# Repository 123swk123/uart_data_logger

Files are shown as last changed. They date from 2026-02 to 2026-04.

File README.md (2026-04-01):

# UART data logger to SD card

> [!NOTE]
> *Work in progress...*

This is a simple UART data logger, logger saves the data to FAT(12/16/32) formatted SD card.

## Schematic

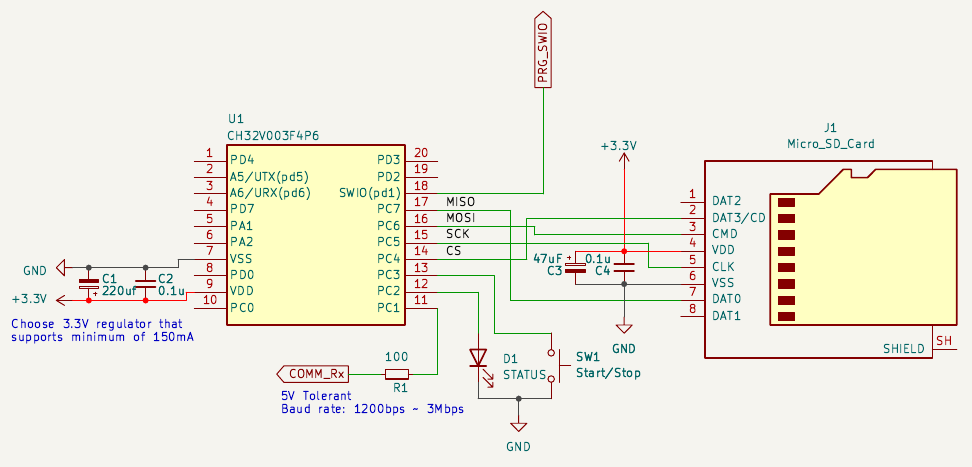
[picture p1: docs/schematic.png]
Schematic

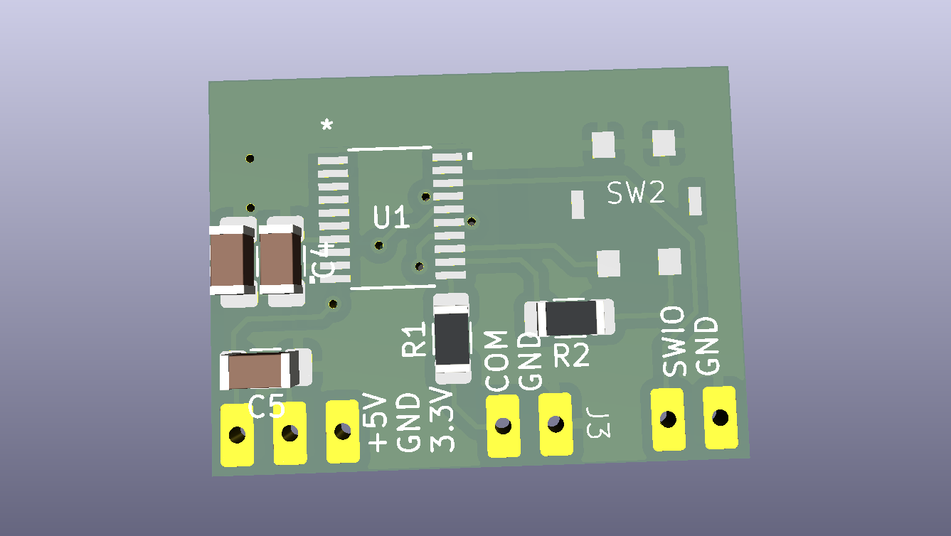
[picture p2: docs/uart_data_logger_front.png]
PCB Front

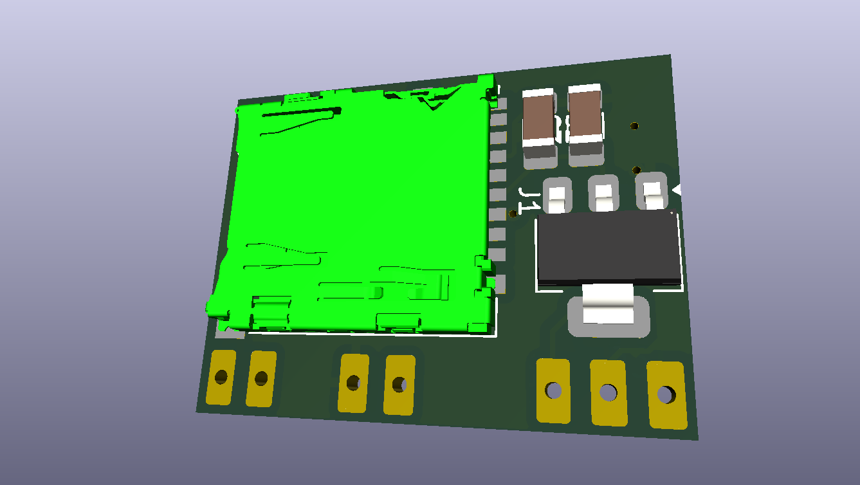
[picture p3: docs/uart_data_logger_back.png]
PCB Back


## Preparations

- Any SDHC card should work, but I have tested them upto 8GB
- Format the card as FAT12/16/32
- copy the [config.txt](src/card_config/config.txt) and [head](src/card_config/head) to root of the SD card

## How to use the logger

- After power-on the status LED will be OFF
- start/stop button is a simple toggle switch
    - press once to start logging
    - press again to stop logging
- Always remove the card when status LED is OFF.

| Status LED | Remarks |
|--|--|
| OFF | Logger stopped, free to remove the SD card after powering down |
| ON | Logger running, do not remove the card |
| Constant blinking | Logger error |
| Brief pulsing |  Actively logging the received UART data |

### config.txt

first 2 lines are comment and they are skipped during the configuration process

3rd line describes the serial port configuration.
> `s<no>:baud rate,data bits<8,9>,parity<0,1,2>,stop bits<1,2>,output formatter<c,d,x,X>,seq start char,seq end char`
```
s<no>:    Serial port number, starting from 1
range:    1 to Maximum no.of UART HW supported by the controller, in case of CH32V003 its just 1.
Example:  s1
```
```
baud rate:  UART logger baud rate
range:      1200 ~ 300000 (check CH32v003 reference manual to calculate the percentage error due to divider round off)
Example:    115200
```
```
data bits:  UART logger data bits per frame
range:      8, 9
Example:    8
```
```
parity:   UART data partiy enable/disable
range:    0 - No parity (disabled)
          1 - odd parity
          2 - even parity
Example:  0
```
```
stop bits:  No.of stop bits per frame
range:      1, 2
Example:    1
```
```
output formatter: logger output encode format
range:            c - store the UART data in a transparent 8-bit ASCII raw
                  u - store the UART data as unsigned decimal value
                  x - store the UART data as hexadecimal value
                  X - store the UART data as hexadecimal value (all caps)
Example:          x
```
```
seq start char: a 9-bit unsigned integer. Upon reciving this character logger notes the event time stamp at start of the row/line
                and the logger continues to log the sub-sequent received data in the same row/line as per the output format
                Note: This seq start character will not be logged.
                      time stamp format: hour.minute.seconds.milli second (resolution: 100milli)
range:          0 ~ 511
Example:        13 (\r)
```
```
seq stop char:  a 9-bit unsigned integer. Upon reciving this character logger closes the current row/line with \r\n and
                creates a new row/line, then the logger waits for seq start character.
                Note: seq stop character will not be logged; Seq start and stop char can be the same.
range:          0 ~ 511
Example:        10 (\n)
```

4th line describes the time offset information.
> `t:year,month,day,hour,minute`
```
t:  start of time offset definition

year:     unsigned 16bit integer
range:    > 1980
Example:  2026

month:    unsigned 16bit integer
range:    1 ~ 12
Example:  2

day:      unsigned 16bit integer
range:    1 ~ 31
Example:  10

hour:     unsigned 16bit integer
range:    0 ~ 23
Example:  22

minute:   unsigned 16bit integer
range:    0 ~ 59
Example:  0
```

### Reasons for logger error

1. SD card not present
2. SD card format not recognized, so unable to mount
3. missing [config.txt](src/card_config/config.txt) in the root of SD card
4. missing [head](src/card_config/head) in the root of SD card
5. Invalid / Un-recognizable contents in [config.txt](src/card_config/config.txt) or [head](src/card_config/head)

## [How to build](docs/build.md)

## Tested features

> [!WARNING]
> Not all aspects of the functionality was tested (This was a side project)

- SDHC card upto 8GB
- Tested baud
  - 115200
  - 750000
  - 921600
- Data bits
  - 8
  - 9
- Parity
  - None
- Stop bits
  - 2
- Logging format
  - `c` - ASCII characters
  - `u` - unsigned decimal
  - `x`/`X` - Hexadecimal
- Seq start/Seq stop
  - `\r`
  - `0xFF`
  - `0x1CC`

### Sample log output
[Test log results](docs/log_output.md)

### Thanks to various open source code base helped realizing the project

- Framework [ch32fun](https://github.com/cnlohr/ch32fun)
- SD Card driver [modified sample driver from ChaN](https://elm-chan.org/docs/mmc/mmc_e.html)
- FAT(12/16/32) library [ChaN's FatFs](https://elm-chan.org/fsw/ff/)
- [Aleksej Muratov's sscanf](https://github.com/MuratovAS/mini-scanf) modified for this project to further reduce the ROM size

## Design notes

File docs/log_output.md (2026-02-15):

# Logger output

This logger in [APP_CONF_RUNNING_LOG](../src/app/uart_logger/Makefile#L14) mode simply creates a log file with running number under the root directory.
Every time when you push the key to start logging, logger reads the [head](../src/card_config/head) file to find the last used log file name and creates the next one.

## SD card root folder listing
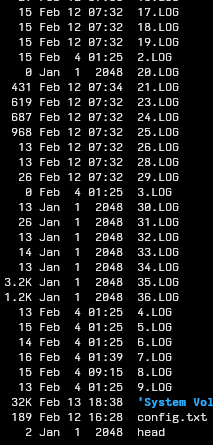
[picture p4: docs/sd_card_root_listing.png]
Logger SD card


## Log file output

### [test1 - 8bit ASCII/transparent logging](../tests/test1.tio.lua) @ 921600bps
```log
[0:5:11.0]ASCII test line 1
[0:5:15.100]ASCII test line 2
[0:5:15.200]Dolor pariatur ipsum nisi dolore culpa in sunt Lorem est. Elit exercitation ut cillum minim velit consequat irure laboris voluptate aliqua ex nisi eu incididunt. Labore excepteur ut pariatur labore culpa esse cillum irure ex cillum sunt fugiat do nisi. Officia irure excepteur ad sint pariatur dolor. Tempor dolor tempor laborum.
[0:5:15.300]Esse non do amet pariatur esse proident. Irure labore cillum est commodo. C consequat.
[0:5:15.300]Lorem labore voluptate officia non deserunt laboris ea. Nulla officia nulla sint deserunt quis ullamco sint laborum. Anim excepteur cillum dolor consequat laborum occaecat dolor minim. Aute nisi ullamco excepteur qui minim duis ex. Dolore deserunt in fugiat ex non elit quis id laboris pariatur minim. Velit aliqua ad consectetur nostrud id enim culpa commodo dolore incididunt incididunt. Cillum veniam consectetur labore consectetur quis ea quis excepteur. Do est aute reprehenderit dolor culpa ea in fugiat consectetur consectetur culpa consequat voluptate.
[0:5:15.400]Elit labore voluptate tempor est nostrud consequat esse enim et consectetur. Velit cupidatat aliqua commodo irure magna eiusmod ea duis ullamco eu voluptate laborum id occaecat. Aliquip deserunt proident exercitation. Sit aliquip sit elit consectetur nulla dolor consectetur dolor occaecat cupidatat proident veniam ea qui laboris. Pariatur esse dolor anim. Non laborum duis nulla laborum fugiat tempor quis cillum aliqua anim.
[0:5:15.500]Reprehenderit aliqua ut pariatur laboris dolor pariatur ex proident aute aliqua veniam Lorem elit ex. Id est elit qui ipsum id consequat deserunt enim eu eiusmod sit labore quis. Sunt et minim officia labore occaecat et anim commodo non ex cillum irure amet Lorem dolor. Eu pariatur culpa irure in aliqua amet non pariatur eu exercitation Lorem.
```

### [test2 - hexadecimal encoded logging](../tests/test2.tio.lua) @ 921600bps
```log
[0:23:15.800]1 2 3 4 5 6 7 8 9 a b c 
[0:23:26.800]e f 
[0:23:26.800]1 2 3 4 5 6 7 8 9 a b c 
[0:23:26.900]e f 10 11 12 13 14 15 16 17 18 19 1a 1b 1c 1d 1e 1f 
[0:23:26.900]1 2 3 4 5 6 7 8 9 a b c 
[0:23:27.0]e f 10 11 12 13 14 15 16 17 18 19 1a 1b 1c 1d 1e 1f 20 21 22 23 24 25 26 27 28 29 2a 2b 2c 2d 2e 2f 30 31 32 33 34 35 36 37 38 39 3a 3b 3c 3d 3e 3f 
[0:23:27.0]1 2 3 4 5 6 7 8 9 a b c 
[0:23:27.0]e f 10 11 12 13 14 15 16 17 18 19 1a 1b 1c 1d 1e 1f 20 21 22 23 24 25 26 27 28 29 2a 2b 2c 2d 2e 2f 30 31 32 33 34 35 36 37 38 39 3a 3b 3c 3d 3e 3f 40 41 42 43 44 45 46 47 48 49 4a 4b 4c 4d 4e 4f 50 51 52 53 54 55 56 57 58 59 5a 5b 5c 5d 5e 5f 60 61 62 63 64 65 66 67 68 69 6a 6b 6c 6d 6e 6f 70 71 72 73 74 75 76 77 78 79 7a 7b 7c 7d 7e 7f 
[0:23:27.0]1 2 3 4 5 6 7 8 9 a b c 
[0:23:27.100]e f 10 11 12 13 14 15 16 17 18 19 1a 1b 1c 1d 1e 1f 20 21 22 23 24 25 26 27 28 29 2a 2b 2c 2d 2e 2f 30 31 32 33 34 35 36 37 38 39 3a 3b 3c 3d 3e 3f 40 41 42 43 44 45 46 47 48 49 4a 4b 4c 4d 4e 4f 50 51 52 53 54 55 56 57 58 59 5a 5b 5c 5d 5e 5f 60 61 62 63 64 65 66 67 68 69 6a 6b 6c 6d 6e 6f 70 71 72 73 74 75 76 77 78 79 7a 7b 7c 7d 7e 7f 80 81 82 83 84 85 86 87 88 89 8a 8b 8c 8d 8e 8f 90 91 92 93 94 95 96 97 98 99 9a 9b 9c 9d 9e 9f a0 a1 a2 a3 a4 a5 a6 a7 a8 a9 aa ab ac ad ae af b0 b1 b2 b3 b4 b5 b6 b7 b8 b9 ba bb bc bd be bf c0 c1 c2 c3 c4 c5 c6 c7 c8 c9 ca cb cc cd ce cf d0 d1 d2 d3 d4 d5 d6 d7 d8 d9 da db dc dd de df e0 e1 e2 e3 e4 e5 e6 e7 e8 e9 ea eb ec ed ee ef f0 f1 f2 f3 f4 f5 f6 f7 f8 f9 fa fb fc fd fe ff
```

### [test3 - decimal encoded logging](../tests/test3.tio.lua) @ 921600bps
```log
[0:0:4.200]0 1 2 3 4 5 6 7 8 9 10 11 12 13 14 15 
[0:1:14.200]0 1 2 3 4 5 6 7 8 9 10 11 12 13 14 15 16 17 18 19 20 21 22 23 24 25 26 27 28 29 30 31 
[0:1:15.200]0 1 2 3 4 5 6 7 8 9 10 11 12 13 14 15 16 17 18 19 20 21 22 23 24 25 26 27 28 29 30 31 32 33 34 35 36 37 38 39 40 41 42 43 44 45 46 47 48 49 50 51 52 53 54 55 56 57 58 59 60 61 62 63 
[0:1:16.200]0 1 2 3 4 5 6 7 8 9 10 11 12 13 14 15 16 17 18 19 20 21 22 23 24 25 26 27 28 29 30 31 32 33 34 35 36 37 38 39 40 41 42 43 44 45 46 47 48 49 50 51 52 53 54 55 56 57 58 59 60 61 62 63 64 65 66 67 68 69 70 71 72 73 74 75 76 77 78 79 80 81 82 83 84 85 86 87 88 89 90 91 92 93 94 95 96 97 98 99 100 101 102 103 104 105 106 107 108 109 110 111 112 113 114 115 116 117 118 119 120 121 122 123 124 125 126 127 
[0:1:17.200]0 1 2 3 4 5 6 7 8 9 10 11 12 13 14 15 16 17 18 19 20 21 22 23 24 25 26 27 28 29 30 31 32 33 34 35 36 37 38 39 40 41 42 43 44 45 46 47 48 49 50 51 52 53 54 55 56 57 58 59 60 61 62 63 64 65 66 67 68 69 70 71 72 73 74 75 76 77 78 79 80 81 82 83 84 85 86 87 88 89 90 91 92 93 94 95 96 97 98 99 100 101 102 103 104 105 106 107 108 109 110 111 112 113 114 115 116 117 118 119 120 121 122 123 124 125 126 127 128 129 130 131 132 133 134 135 136 137 138 139 140 141 142 143 144 145 146 147 148 149 150 151 152 153 154 155 156 157 158 159 160 161 162 163 164 165 166 167 168 169 170 171 172 173 174 175 176 177 178 179 180 181 182 183 184 185 186 187 188 189 190 191 192 193 194 195 196 197 198 199 200 201 202 203 204 205 206 207 208 209 210 211 212 213 214 215 216 217 218 219 220 221 222 223 224 225 226 227 228 229 230 231 232 233 234 235 236 237 238 239 240 241 242 243 244 245 246 247 248 249 250 251 252 253
```

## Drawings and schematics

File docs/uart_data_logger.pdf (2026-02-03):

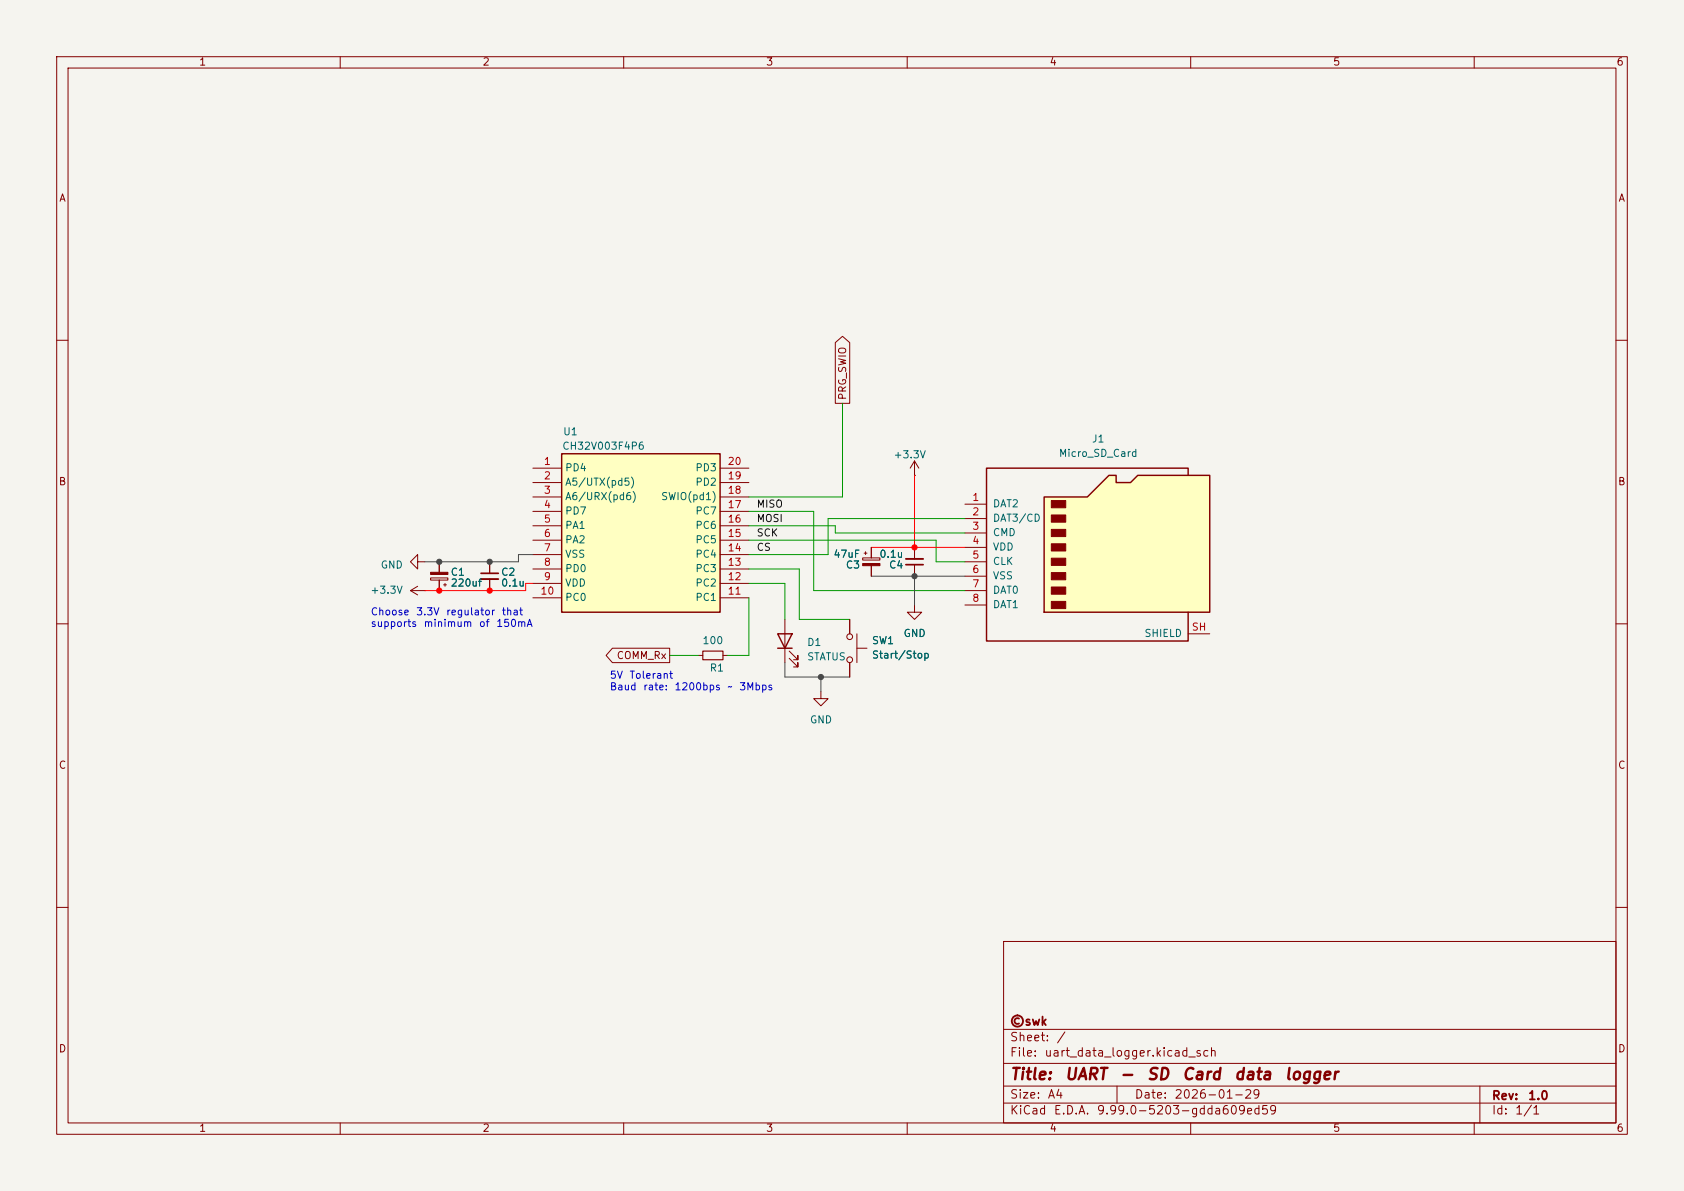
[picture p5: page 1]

Sheet: /
D Date: 2026-01-29 KiCad E.D.A. 9.99.0-5203-gdda609ed59
File: uart_data_logger.kicad_sch
Title: UART - SD Card data logger

Size: A4 | Rev: 1.0

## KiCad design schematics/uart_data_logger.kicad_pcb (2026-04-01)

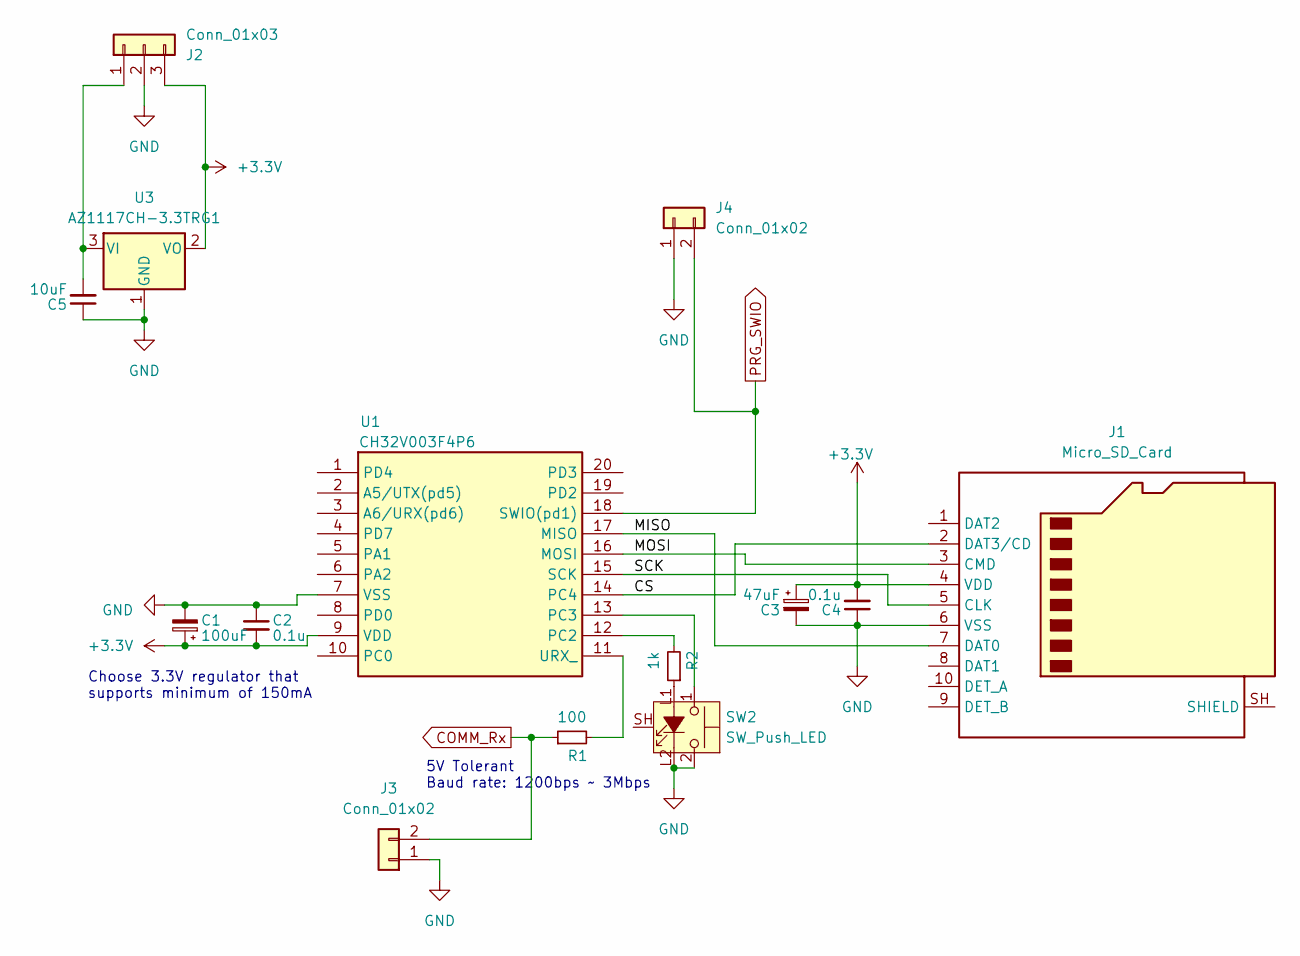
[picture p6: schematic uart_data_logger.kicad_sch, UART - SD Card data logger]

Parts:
C1: 100uF; C_1206_3216Metric_Pad1.33x1.80mm_HandSolder
C2, C4: 0.1u; C_1206_3216Metric_Pad1.33x1.80mm_HandSolder
C3: 47uF; C_1206_3216Metric_Pad1.33x1.80mm_HandSolder
C5: 10uF; C_1206_3216Metric_Pad1.33x1.80mm_HandSolder
J1: Micro_SD_Card; microSD_HC_Hirose_DM3AT-SF-PEJM5
J2: Conn_01x03; 1x03_THT_P2.54mm
J3, J4: Conn_01x02; 1x02_THT_P2.54mm
R1: 100; R_1206_3216Metric_Pad1.30x1.75mm_HandSolder
R2: 1k; R_1206_3216Metric_Pad1.30x1.75mm_HandSolder
SW2: SW_Push_LED; SW_Push_LED_AK104238
U1: CH32V003F4P6; TSSOP20
U3: AZ1117CH-3.3TRG1; SOT-223-3_TabPin2

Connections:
+3.3V: C1.1, C2.2, C3.1, C4.2, J1.4 (VDD), J2.3, U1.9 (VDD), U3.2 (VO)
/CS: J1.2 (DAT3/CD), U1.14 (PC4)
/MISO: J1.7 (DAT0), U1.17 (MISO)
/MOSI: J1.3 (CMD), U1.16 (MOSI)
/SCK: J1.5 (CLK), U1.15 (SCK)
COMM_Rx: J3.2, R1.1
GND: C1.2, C2.1, C3.2, C4.1, C5.1, J1.6 (VSS), J2.2, J3.1, J4.1, SW2.2, SW2.L2, U1.7 (VSS), U3.1 (GND)
unnamed: C5.2, J2.1, U3.3 (VI)
unnamed: R2.1, SW2.L1
unnamed: R1.2, U1.11 (URX_)
unnamed: R2.2, U1.12 (PC2)
unnamed: SW2.1, U1.13 (PC3)
PRG_SWIO: J4.2, U1.18 (SWIO(pd1))

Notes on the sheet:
5V Tolerant Baud rate: 1200bps ~ 3Mbps
Choose 3.3V regulator that supports minimum of 150mA

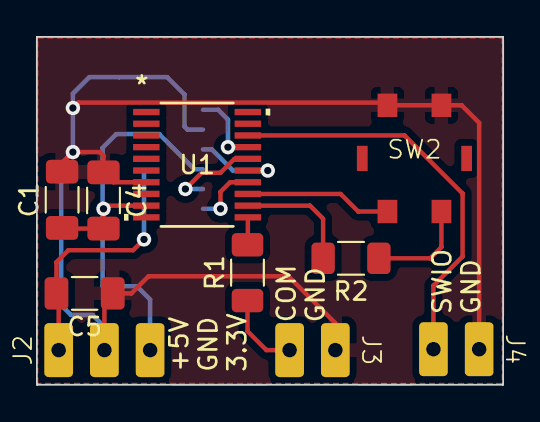
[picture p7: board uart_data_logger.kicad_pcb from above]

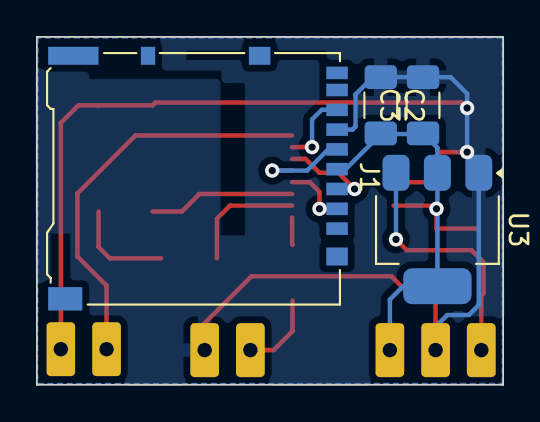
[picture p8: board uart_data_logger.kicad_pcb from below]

Board: 2 copper layers, 25.9 x 19.3 mm, 14 parts (4 on the bottom side), 13 nets.

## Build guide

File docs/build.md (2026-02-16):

# To Build...

## RISCV gcc toolchain

Download and extract either one of those based on your Ubuntu version and ensure that `bin` folder of the extracted path is in your environment variable's `PATH` list

[riscv64-uclibc-ng-ubuntu-22.04-gcc.tar.xz](https://github.com/riscv-collab/riscv-gnu-toolchain/releases/download/2026.02.13/riscv64-uclibc-ng-ubuntu-22.04-gcc.tar.xz)
[riscv64-uclibc-ng-ubuntu-24.04-gcc.tar.xz](https://github.com/riscv-collab/riscv-gnu-toolchain/releases/download/2026.02.13/riscv64-uclibc-ng-ubuntu-24.04-gcc.tar.xz)

## Compilation

Walk through the [Makefile]() and [app_base.h]() to understand the available various pre-compilation options.
by the way the default setting is the optimized version that is suitable for most of the use case(s)

### To compile without any debug print

> [!NOTE]
> Debug print uses semi-hosting mechanism to send the log that are invoked via printf(...) calls, so you need debugger connected to view the logs

`make -C src/app/uart_logger DEBUG=0`

### To compile with debug print

`make -C src/app/uart_logger`

### To generate intellisense support file

`make -C src/app/uart_logger clangd`

### To clean

`make -C src/app/uart_logger clangd_clean clean`

## [Pre-built binaries](https://github.com/123swk123/uart_data_logger/releases)

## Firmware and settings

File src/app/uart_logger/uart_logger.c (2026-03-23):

#include "drv_systick.h"
#include "app_base.h"

#include "ch32fun.h"
#include "ch32v003hw.h"
#include "ff.h"

#if (FF_MULTI_PARTITION == 1)
PARTITION VolToPart[FF_VOLUMES] = {
  {0, 1},     /* "0:" ==> 1st partition on the pd#0 */
};
#endif

FATFS gFsFAT;
FIL ghFile;

static uint16_t gu16buffRx[APP_UART_RX_BUFF_SZ];

#if (APP_CONF_CACHE_BUFF)
char gbuffCache[FF_MIN_SS+30];
static uint32_t gidxCacheWr = 0;
#endif

stHMI gHMI;
stCFGLog gCfgLog;

int _write(int fd,
           const char *buf,
           int size) {
  int i = 0;
  int writeSize = size;

  #if 0
  volatile union {
    uint32_t u32;
    struct {
      uint8_t b3;
      uint8_t b4;
      uint8_t b5;
      uint8_t b6;
    };
  } *data1;
  volatile union {
    uint32_t u32;
    struct {
      uint8_t sz;
      uint8_t b0;
      uint8_t b1;
      uint8_t b2;
    };
  } *data0 = (void *)&size;
  #endif
  do {
    /**
     * data0  data1 8 bytes
     * data0 The lowest byte storage length, the maximum is 7
     *
     */
    while (*(DMDATA0) != 0u)
      ;

    if (writeSize > 7) {
      *(DMDATA1) = (*(buf + i + 3)) | (*(buf + i + 4) << 8) | (*(buf + i + 5) << 16) | (*(buf + i + 6) << 24);
      // data1.b3 = *(buf+i+3);
      // data1.b4 = *(buf+i+4);
      // data1.b5 = *(buf+i+5);
      // data1.b6 = *(buf+i+6);
      // *(DMDATA1) = data1.u32;

      *(DMDATA0) = (7u) | (*(buf + i) << 8) | (*(buf + i + 1) << 16) | (*(buf + i + 2) << 24);
      // data0->b2 = *(buf+i+2);
      // data0->b1 = *(buf+i+1);
      // data0->b0 = *(buf+i+0);
      // data0->sz = writeSize;
      // *(DMDATA0) = data0->u32;

      i += 7;
      writeSize -= 7;
    } else {
      *(DMDATA1) = (*(buf + i + 3)) | (*(buf + i + 4) << 8) | (*(buf + i + 5) << 16) | (*(buf + i + 6) << 24);
      // data1.b3 = *(buf+i+3);
      // data1.b4 = *(buf+i+4);
      // data1.b5 = *(buf+i+5);
      // data1.b6 = *(buf+i+6);
      // *(DMDATA1) = data1.u32;

      *(DMDATA0) = (writeSize) | (*(buf + i) << 8) | (*(buf + i + 1) << 16) | (*(buf + i + 2) << 24);
      // data0->b2 = *(buf+i+2);
      // data0->b1 = *(buf+i+1);
      // data0->b0 = *(buf+i+0);
      // data0->sz = writeSize;
      // *(DMDATA0) = data0->u32;

      writeSize = 0;
    }
  } while (writeSize);
  return size;
}

static char *_f_gets(char *buff,
                     FIL *f) {
  UINT nBytesAccessed;
  char c = '\0';

  if (buff == NULL) {
    // skip this line
    while (c != '\n') {
      f_read(f, &c, 1, &nBytesAccessed);
      if (nBytesAccessed == 0) {
        break;
      }
    }
    return buff;
  } else {
    while (c != '\n') {
      f_read(f, &c, 1, &nBytesAccessed);
      if (nBytesAccessed == 0) {
        *buff++ = '\0';
        break;
      }
      if (c == '\n')
        *buff++ = '\0';
      else if (c != '\r')
        *buff++ = c;
    }
    return buff;
  }
}

static inline FRESULT doConfig(void) {
  FRESULT rslt = f_open(&ghFile, "config.txt", FA_READ);
  int tmp;
  if (rslt == FR_OK) {
    #if (APP_CONF_CACHE_BUFF == 1)
    #define buff gbuffCache
    #else
    char buff[40];
    #endif
    char *pBuff;
    struct {
      uint32_t uBaud;
      uint32_t uBits;
      uint32_t uParity;
      uint32_t uStop;
    } cfgUART;

// skip the first 2 comment line
#if 0
        UINT nBytesAccessed;
        tmp = 0;
        while(tmp < 2) {
            f_read(&ghFile, buff, 1, &nBytesAccessed);
            if(nBytesAccessed == 0) {rslt = FR_INVALID_PARAMETER;goto _doConfig_Exit;}
            if(buff[0] == '\n')
                tmp++;
        }
#else
    _f_gets(NULL, &ghFile);
    _f_gets(NULL, &ghFile);
#endif

    // read uart1 config
    // pBuff = f_gets(buff, sizeof(buff)-1, &ghFile);
    pBuff = _f_gets(buff, &ghFile);
    if (pBuff == 0) {
      rslt = FR_INVALID_PARAMETER;
      goto _doConfig_Exit;
    }
    puts_dbg(buff);
    // skip first 3 chars 's1:'
    tmp = c_sscanf(&buff[3], "%u%u%u%u%*c%c%u%u", &cfgUART.uBaud, &cfgUART.uBits, &cfgUART.uParity, &cfgUART.uStop,
                   &gCfgLog.cOutputFormatter, &gCfgLog.uSeqStart, &gCfgLog.uSeqStop);
    printf_dbg("s1:%u,%u,%u,%u,%u,%u,%c|\n", cfgUART.uBaud, cfgUART.uBits, cfgUART.uParity, cfgUART.uStop, gCfgLog.uSeqStart,
            gCfgLog.uSeqStop, gCfgLog.cOutputFormatter);
    if (tmp != 8) {
      rslt = FR_INVALID_PARAMETER+1;
      goto _doConfig_Exit;
    }

#define CTLR1_UE_Set   ((uint16_t)0x2000) /* USART Enable Mask */
#define CTLR1_UE_Reset ((uint16_t)0xDFFF) /* USART Disable Mask */
                                          // re-initialize the UART with user-given parameters

#if 1
    // disable USART1
    USART1->CTLR1 = 0;
    USART1->STATR = 0;
    // Rx Enabled
    tmp = USART_CTLR1_RE;
    if (cfgUART.uBits == 9) {
      tmp |= USART_CTLR1_M;
    }
    if (cfgUART.uParity == 1) // Odd-parity
      tmp |= USART_CTLR1_PCE | USART_CTLR1_PS;
    if (cfgUART.uParity == 2) // Even-parity
      tmp |= USART_CTLR1_PCE;
    USART1->CTLR1 = tmp;

    // for CTLR2
    // Stop bits 1 or 2
    USART1->CTLR2 = (cfgUART.uStop == 1) ? (0b00 << 12) : (0b10 << 12);

    // DMAR:En
    USART1->CTLR3 = USART_CTLR3_DMAR;

    UART_DMA_Rx->CFGR = 0;
    UART_DMA_Rx->PADDR = (ptrdiff_t)&USART1->DATAR;
    UART_DMA_Rx->MADDR = (ptrdiff_t)gu16buffRx;
    UART_DMA_Rx->CNTR = APP_UART_RX_BUFF_SZ;
    UART_DMA_Rx->CFGR = DMA_DIR_PeripheralSRC | DMA_PeripheralInc_Disable | DMA_MemoryInc_Enable |
                        DMA_PeripheralDataSize_HalfWord | DMA_MemoryDataSize_HalfWord | DMA_Mode_Circular |
                        DMA_Priority_VeryHigh | DMA_M2M_Disable;

  #if 0
        uint32_t integerdivider = ((25 * SYSCLK_FREQ) / (4 * cfgUART.uBaud));
        uint32_t tmpreg = (integerdivider / 100) << 4;
        uint32_t fractionaldivider = integerdivider - (100 * (tmpreg >> 4));
        tmpreg |= ((((fractionaldivider * 16) + 50) / 100)) & ((uint8_t)0x0F);
        USART1->BRR = tmpreg;
  #elif 0
    uint32_t integerdivider = ((SYSCLK_FREQ >> 4) * 100) / cfgUART.uBaud;
    USART1->BRR = integerdivider / 100; //(SYSCLK_FREQ>>4)/cfgUART.uBaud;
    integerdivider -= USART1->BRR * 100;
    USART1->BRR = (USART1->BRR << 4) | (integerdivider / 6);
  #else
    // div=(Fsys/16)*128/baud               => ((Fsys >> 4) << 7)/baud
    // fra=(div-((div/128)*128))/(128/16)   => (div - (div & 0xFFFF_FF80)) >> 3
    // baud=int(384e3);div=(fsys>>4<<7)//baud;reg=((div & 0xFFFF_FF80)>>3)|((div &
    // 0x7f)>>3);divisor=(reg>>4)+((reg&0x0f)/16);act_baud=fsys//16//divisor;print(f'{div/128} -> {reg} =>
    // {divisor}:{act_baud}bps:{((baud-act_baud)*100)/baud:.04}%')
    USART1->BRR = ((SYSCLK_FREQ >> 4) << 7) / cfgUART.uBaud;
    USART1->BRR = ((USART1->BRR & 0xFFFFFF80) >> 3) | ((USART1->BRR & 0x7F) >> 3);
  #endif

    USART1->GPR = 0;

    USART1->CTLR1 |= USART_CTLR1_UE;
    printf_dbg("%04X, %04X, %04X, %04X\n", USART1->CTLR1, USART1->CTLR2, USART1->CTLR3, USART1->BRR);
#endif

    // read configured time
    // pBuff = f_gets(buff, sizeof(buff)-1, &ghFile);
    #if (APP_CONF_RELOAD_TIME_ON_START == 0)
    if(gTime.uYear < 1980)
    #endif
    {
      pBuff = _f_gets(buff, &ghFile);
      if (pBuff == 0) {
        rslt = FR_INVALID_PARAMETER+2;
        goto _doConfig_Exit;
      }
      puts_dbg(buff);
      tmp = c_sscanf(&buff[2], "%u%u%u%u%u", &gTime.uYear, &gTime.uMonth, &gTime.uDay, &gTime.uHour, &gTime.uMinute);
      printf_dbg("t:%u,%u,%u,%u,%u\n", gTime.uYear, gTime.uMonth, gTime.uDay, gTime.uHour, gTime.uMinute);
      gTime.uSecond = gTime.uMilliSec = 0;
      if (tmp != 5) {
        rslt = FR_INVALID_PARAMETER;
        goto _doConfig_Exit;
      }
    }
  }
_doConfig_Exit:
  f_close(&ghFile);
  return rslt;
  #if (APP_CONF_CACHE_BUFF == 1)
    #undef buff
  #endif
}

#if (APP_CONF_RUNNING_LOG == 0)
static inline FRESULT doCreateNewLog(void) {
  char buff[12+1];
  // DDhhmmss.log <-- short file name
  char *pBuff = buff;

  pBuff += mini_itoa(gTime.uDay, 10, 0, 1, pBuff);
  // *pBuff++ = '_';
  pBuff += mini_itoa(gTime.uHour, 10, 0, 1, pBuff);
  // *pBuff++ = '_';
  pBuff += mini_itoa(gTime.uMinute, 10, 0, 1, pBuff);
  // *pBuff++ = '_';
  pBuff += mini_itoa(gTime.uSecond, 10, 0, 1, pBuff);

  *pBuff++ = '.';
  *pBuff++ = 'l';
  *pBuff++ = 'o';
  *pBuff++ = 'g';
  *pBuff++ = '\0';

  puts_dbg(buff);
  FRESULT rslt = f_open(&ghFile, buff, FA_CREATE_NEW | FA_WRITE);
  if (rslt == FR_OK) {
    return rslt;
  }

  f_close(&ghFile);
  return rslt;
}
#else
static inline FRESULT doCreateNewLog(void) {
  FRESULT rslt = f_open(&ghFile, "head", FA_READ | FA_WRITE);
  if (rslt == FR_OK) {
    #if (APP_CONF_CACHE_BUFF == 1)
    #define buff gbuffCache
    #else
    char buff[16];
    #endif
    UINT nBytesAccessed;
    int tmp;
#define nFileIdx nBytesAccessed

    if (f_size(&ghFile) >= sizeof(buff)) {
      rslt = FR_INVALID_PARAMETER;
      goto _doCreateNewLog_Exit;
    }

    rslt = f_read(&ghFile, buff, sizeof(buff), &nBytesAccessed);
    if (rslt != FR_OK) {
      goto _doCreateNewLog_Exit;
    }
    rslt = f_rewind(&ghFile);
    if (rslt != FR_OK) {
      goto _doCreateNewLog_Exit;
    }
    buff[nBytesAccessed] = '\0';
    tmp = c_sscanf(buff, "%u", &nFileIdx);
    if (tmp != 1) {
      rslt = FR_INVALID_PARAMETER;
      goto _doCreateNewLog_Exit;
    }
    // tmp = sprintf_(buff, "%d", ++nFileIdx);
    tmp = mini_itoa(++nFileIdx, 10, 0, 1, buff);
    char *pBuff = &buff[tmp];
    rslt = f_write(&ghFile, buff, tmp, &nBytesAccessed);
    if (rslt != FR_OK) {
      goto _doCreateNewLog_Exit;
    }
    f_close(&ghFile);

    *pBuff++ = '.';
    *pBuff++ = 'l';
    *pBuff++ = 'o';
    *pBuff++ = 'g';
    *pBuff++ = '\0';
    puts_info(buff);
    rslt = f_open(&ghFile, buff, FA_CREATE_NEW | FA_WRITE);
    return rslt;

#undef nFileIdx
  } else {
    return rslt;
  }
_doCreateNewLog_Exit:
  f_close(&ghFile);
  return rslt;
  #if (APP_CONF_CACHE_BUFF == 1)
    #undef buff
  #endif
}
#endif

#if (APP_CONF_CACHE_BUFF) 
static inline int doWriteLog(uint16_t val) {
  UINT nBytesAccessed;

  #define cacheWrite(x) gbuffCache[gidxCacheWr++]=x
  #define cacheWritePtr &gbuffCache[gidxCacheWr]
  #define cacheWriterInc() gidxCacheWr++

  APP_STATUS_LED1_OFF();

  if (val == gCfgLog.uSeqStart) {
    if (val == gCfgLog.uSeqStop) {
      cacheWrite('\r');
      cacheWrite('\n');
    }
    cacheWrite('[');
    gidxCacheWr += mini_itoa(gTime.uHour, 10, 0, 1, cacheWritePtr);
    cacheWrite(':');
    gidxCacheWr += mini_itoa(gTime.uMinute, 10, 0, 1, cacheWritePtr);
    cacheWrite(':');
    gidxCacheWr += mini_itoa(gTime.uSecond, 10, 0, 1, cacheWritePtr);
    cacheWrite('.');
    gidxCacheWr += mini_itoa(gTime.uMilliSec, 10, 0, 1, cacheWritePtr);
    cacheWrite(']');
  } else if (val == gCfgLog.uSeqStop) {
    cacheWrite('\r');
    cacheWrite('\n');
  } else {
    switch (gCfgLog.cOutputFormatter) {
    case 'u':
      gidxCacheWr += mini_itoa(val, 10, 0, 1, cacheWritePtr);
      cacheWrite(' ');
      break;
    case 'x':
    case 'X':
      gidxCacheWr += mini_itoa(val, 16, (gCfgLog.cOutputFormatter=='X'), 1, cacheWritePtr);
      cacheWrite(' ');
      break;
    case 'c':
    default:
      cacheWrite(val & 0xFF);
    }
  }

_write_buff:
  if(gidxCacheWr >= FF_MIN_SS) {
    NVIC_DisableIRQ(TIM2_IRQn);
    FRESULT tmp = f_write(&ghFile, gbuffCache, FF_MIN_SS, &nBytesAccessed);
    NVIC_EnableIRQ(TIM2_IRQn);
    if (nBytesAccessed == 0) {
      gHMI.u8OperationalState = APP_LOGGING_ERROR;
      printf_err("doWrite: %u\n", tmp);
      return -1;
    }
    gidxCacheWr -= nBytesAccessed;
    if (gidxCacheWr) {
      MEM_DMA_Reset_Mover();
      MEM_DMA_Start_Mover(&gbuffCache[FF_MIN_SS], gidxCacheWr);
    }
    // f_sync(&ghFile);
    return FF_MIN_SS;
  } else {
    return 0;
  }
}
#else
static inline int doWriteLog(uint16_t val) {
  char buff[20];
  UINT nBytesAccessed;
  int bytes2write = 0;

  APP_STATUS_LED1_OFF();

  if (val == gCfgLog.uSeqStart) {
    if (val == gCfgLog.uSeqStop) {
      buff[0] = '\r';
      buff[1] = '\n';
      buff[2] = '[';
      bytes2write = 3;
    } else {
      buff[0] = '[';
      bytes2write = 1;
    }
    bytes2write += mini_itoa(gTime.uHour, 10, 0, 1, &buff[bytes2write]);
    buff[bytes2write++] = ':';
    bytes2write += mini_itoa(gTime.uMinute, 10, 0, 1, &buff[bytes2write]);
    buff[bytes2write++] = ':';
    bytes2write += mini_itoa(gTime.uSecond, 10, 0, 1, &buff[bytes2write]);
    buff[bytes2write++] = '.';
    bytes2write += mini_itoa(gTime.uMilliSec, 10, 0, 1, &buff[bytes2write]);
    buff[bytes2write++] = ']';
  } else if (val == gCfgLog.uSeqStop) {
    buff[0] = '\r';
    buff[1] = '\n';
    bytes2write += 2;
  } else {
    switch (gCfgLog.cOutputFormatter) {
    case 'u':
      bytes2write += mini_itoa(val, 10, 0, 1, buff);
      break;
    case 'x':
    case 'X':
      bytes2write += mini_itoa(val, 16, 0, (gCfgLog.cOutputFormatter=='X'), buff);
      break;
    case 'c':
    default:
      buff[0] = val & 0xFF;
      bytes2write += 1;
    }
  }

_write_buff:
  f_write(&ghFile, &buff, bytes2write, &nBytesAccessed);
  if (nBytesAccessed != bytes2write) {
    gHMI.u8OperationalState = APP_LOGGING_ERROR;
  }

  return bytes2write;
}
#endif

int main(void) {
  SystemInit();

  RCC->APB2PCENR |=
      RCC_APB2Periph_AFIO | RCC_APB2Periph_GPIOC | RCC_APB2Periph_GPIOD | RCC_APB2Periph_SPI1 | RCC_APB2Periph_USART1;
  RCC->APB1PCENR |= RCC_APB1Periph_TIM2;
  RCC->AHBPCENR |= RCC_AHBPeriph_DMA1;

  // dbgGPIO_Init();

  AFIO->PCFR1 = AFIO_PCFR1_USART1_REMAP_1 | AFIO_PCFR1_USART1_REMAP | AFIO_PCFR1_SPI1_REMAP;

  // Timer 2 initialization
  // OC1: OCMode Freeze, Compare Output Disabled, OCR pre-load Disabled
  // TIM2->CH1CVR = 500-1;
  // TIM2->CTLR2 <- No need
  // TIM2->CHCTLR1 <- reset value is good
  // TIM2->CCER <- reset value is good]

  // Timer: Internal Clock, Count Up Mode, CLK_DIV1, Auto-reload Enabled
  TIM2->PSC = 48000 - 1;               // 1khz
  TIM2->ATRLR = APP_TIMER_TICK_PERIOD; // 100 milli-sec
  TIM2->CTLR1 = TIM_ARPE | TIM_CEN | TIM_URS;
  // TIM2->SWEVGR = TIM_EventSource_Trigger;//TIM_PSCReloadMode_Immediate;
  // TIM2->SMCFGR <- reset value is good
  TIM2->DMAINTENR = TIM_IT_Update;

  #if APP_CONF_CACHE_BUFF
  MEM_DMA_Mover->CFGR = 0;
  MEM_DMA_Mover->MADDR = (ptrdiff_t)gbuffCache;
  MEM_DMA_Mover->CFGR = DMA_DIR_PeripheralSRC | DMA_PeripheralInc_Enable | DMA_MemoryInc_Enable |
                        DMA_PeripheralDataSize_Byte | DMA_MemoryDataSize_Byte |
                        DMA_Mode_Normal | DMA_Priority_Low | DMA_M2M_Enable;
  #endif

  gCfgLog.cOutputFormatter = gTime.uYear = 0;
  gHMI.u8OperationalState = APP_LOGGING_OFF;
  gHMI.u8zKey = GPIOC->INDR & APP_KEY_START_STOP;

  NVIC_EnableIRQ(TIM2_IRQn);
  __enable_irq();

  while (1) {
    if (gHMI.u8OperationalState == APP_LOGGING_ON) {
      FRESULT tmp = f_mount(&gFsFAT, "0:", 0); // lazy mount, saves some 100bytes of ROM
      printf_info("mount: %u\n", tmp);
      if (tmp == FR_OK) {
        #if (APP_CONF_RELOAD_CFG_ON_START == 0)
        if (gCfgLog.cOutputFormatter == 0)
        #endif
        {
          tmp = doConfig();
        }

        if (tmp == FR_OK) {
          tmp = doCreateNewLog();
          if (tmp == FR_OK) {
            // do the first header write
            doWriteLog(gCfgLog.uSeqStart);

            // Delay_Ms(500);
            tmp = drvSystick_Offset_Setms(500);
            while (drvSystick_Offset_Running(tmp));

            UART_DMA_Rx->MADDR = (ptrdiff_t)gu16buffRx;
            UART_DMA_Rx->CNTR = APP_UART_RX_BUFF_SZ;
            UART_DMA_Rx->CFGR |= DMA_CFGR1_EN;
            // uint16_t* tail = &gu16buffRx[0];
            volatile uint32_t tail = 0;
            #if APP_CONF_CACHE_BUFF
            gidxCacheWr = 0;
            #endif

            while (gHMI.u8OperationalState == APP_LOGGING_ON) {
              // while(USART_GetFlagStatus(USART1, USART_FLAG_RXNE) == RESET);
              // while((USART1->STATR & USART_FLAG_RXNE) == 0);
              // uint16_t tmp = USART1->DATAR;//USART_ReceiveData(USART1);

              #if 0
              uint16_t* head = &gu16buffRx[APP_UART_RX_BUFF_SZ] - UART_DMA_Rx->CNTR;
              // dbgDBG1_HIGH();
              while (tail != head) {
                APP_STATUS_LED1_OFF();
                tmp = doWriteLog(*tail++);
                if (tail >= &gu16buffRx[APP_UART_RX_BUFF_SZ]) {
                  tail = &gu16buffRx[0];
                }
              }
              // dbgDBG1_LOW();
              #else
              #define head (APP_UART_RX_BUFF_SZ - UART_DMA_Rx->CNTR)
              // dbgDBG1_HIGH();
              //printf_dbg("%x<->%x\n", tail, head);
              while (tail != head) {
                // APP_STATUS_LED1_OFF();
                tmp = doWriteLog(gu16buffRx[tail]);
                if(((int)tmp) < 0)
                  break;
                tail = (tail+1) % APP_UART_RX_BUFF_SZ;
              }
              // dbgDBG1_LOW();
              #endif

              #if (APP_CONF_PERIODIC_SYNC)
              if (gTime.uPeriodicSync >= 5) {
                // @ every 5 sec if we have written anything
                gTime.uPeriodicSync = 0;
                if ((int)tmp > 0) {
                  NVIC_DisableIRQ(TIM2_IRQn);
                  if (f_sync(&ghFile) != FR_OK) {
                    gHMI.u8OperationalState = APP_LOGGING_ERROR;
                  }
                  NVIC_EnableIRQ(TIM2_IRQn);
                  tmp = 0;
                }
              }
              #endif
            }

            NVIC_DisableIRQ(TIM2_IRQn);
            #if (APP_CONF_CACHE_BUFF)
            if (gidxCacheWr && (gHMI.u8OperationalState == APP_LOGGING_ON)) {
              #define nBytesAccessed tail
              f_write(&ghFile, gbuffCache, gidxCacheWr, (UINT*)&nBytesAccessed);
              gidxCacheWr = 0;
              #undef nBytesAccessed
            }
            #endif

            f_close(&ghFile);
            NVIC_EnableIRQ(TIM2_IRQn);
          } else {
            printf_err("doCreateNewLog:%u\n", tmp);
            gHMI.u8OperationalState = APP_LOGGING_ERROR;
          }
        } else {
          printf_err("doConfig:%u\n", tmp);
          gHMI.u8OperationalState = APP_LOGGING_ERROR;
        }

        f_unmount("");
        printf_info("Safe removal\n");
      } else {
        gHMI.u8OperationalState = APP_LOGGING_ERROR;
      }
    } else {
      if (gHMI.u8OperationalState == APP_LOGGING_OFF)
        APP_STATUS_LED1_OFF();
      
      // Turn off UART Rx DMA
      UART_DMA_Rx->CFGR &= ~DMA_CFGR1_EN;
    }
  }
}

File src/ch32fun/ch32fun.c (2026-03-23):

// Mixture of embedlibc, and ch32v00x_startup.c
// Use with newlib headers.
// Mixture of weblibc, mini-printf and ???
/* This file contains the following functions:

// libc (via musl) mixture and miniprintf

int printf( const char* format, ... )
int vprintf(const char* format, va_list args)
int snprintf( char * buffer, unsigned int buffer_len, const char* format, ... )
int sprintf( char * buffer, const char * format, ... )
size_t wcrtomb(char *restrict s, wchar_t wc, mbstate_t *restrict st)
int wctomb(char *s, wchar_t wc)
size_t strlen(const char *s)
size_t strnlen(const char *s, size_t n)
void *memset(void *dest, int c, size_t n)
char *strcpy(char *d, const char *s)
char *strncpy(char *d, const char *s, size_t n)
int strcmp(const char *l, const char *r)
int strncmp(const char *_l, const char *_r, size_t n)
static char *twobyte_strstr(const unsigned char *h, const unsigned char *n)
static char *threebyte_strstr(const unsigned char *h, const unsigned char *n)
static char *fourbyte_strstr(const unsigned char *h, const unsigned char *n)
static char *twoway_strstr(const unsigned char *h, const unsigned char *n)
char *strstr(const char *h, const char *n)
char *strchr(const char *s, int c)
void *__memrchr(const void *m, int c, size_t n)
char *strrchr(const char *s, int c)
void *memcpy(void *dest, const void *src, size_t n)
int memcmp(const void *vl, const void *vr, size_t n)
void *memmove(void *dest, const void *src, size_t n)
void *memchr(const void *src, int c, size_t n)
int puts(const char *s)
int mini_itoa(long value, unsigned int radix, int uppercase, int unsig,
	 char *buffer)
int mini_vsnprintf(char *buffer, unsigned int buffer_len, const char *fmt, va_list va)
int mini_vpprintf(int (*puts)(char* s, int len, void* buf), void* buf, const char *fmt, va_list va)
int mini_snprintf(char* buffer, unsigned int buffer_len, const char *fmt, ...)
int mini_pprintf(int (*puts)(char*s, int len, void* buf), void* buf, const char *fmt, ...)

// IRQ Handling Code
void DefaultIRQHandler( void )
void NMI_RCC_CSS_IRQHandler( void )

// Startup Code
void InterruptVectorDefault( void )
void handle_reset( void )

// Configuration-specific I/O

#if defined( FUNCONF_USE_UARTPRINTF ) && FUNCONF_USE_UARTPRINTF
void SetupUART( int uartBRR )
int _write(int fd, const char *buf, int size)
int putchar(int c)
#endif

#if defined( FUNCONF_USE_DEBUGPRINTF ) && FUNCONF_USE_DEBUGPRINTF
void handle_debug_input( int numbytes, uint8_t * data ) // You can override this!
void poll_input( void )
int _write(int fd, const char *buf, int size)
int putchar(int c)
void SetupDebugPrintf( void )
void WaitForDebuggerToAttach()
#endif

#if (defined( FUNCONF_USE_DEBUGPRINTF ) && !FUNCONF_USE_DEBUGPRINTF) && \
	(defined( FUNCONF_USE_UARTPRINTF ) && !FUNCONF_USE_UARTPRINTF) && \
	(defined( FUNCONF_NULL_PRINTF ) && FUNCONF_NULL_PRINTF)

int _write(int fd, const char *buf, int size)
int putchar(int c)
#endif

void DelaySysTick( uint32_t n )
void SystemInit( void )

#ifdef CPLUSPLUS
extern void __cxa_pure_virtual()
void __libc_init_array(void)
#endif

*/

// We pre-define these, because if the user is (for some awful reason) using gcc-riscv64-linux-gnu with newlib, it will fail to compile if it janks up the stdio/string functions.
#define _SSP_STRING_H_
#define _SSP_STDIO_H_

#include <stdio.h>
#include <string.h>
#include <stdarg.h>
#include <limits.h>
#include <stdint.h>
#include <ch32fun.h>

#ifdef __UCLIBC__
#undef putchar
#endif

#if defined(CH32H41x)
volatile v5f_main v5f_start_function = NULL;
static int start_v5f(void)
{
	if (v5f_start_function == NULL)
	{
		asm volatile (
		"li a1, 1\n\
		sw a1, (a0)\n" // deep sleepy time for V5F
		"li a0, 0xE000ED10\n\
		li a1, 0x80000000\n\
		sw a1, (a0)\n" // self-SYSRST when we are not supposed to be running
		);
		return -1;
	}

	return v5f_start_function();
}
#endif

WEAK int errno;

static int __puts_uart( char *s, int len, void *buf )
{
	(void)buf;

	_write( 0, s, len );
	return len;
}

WEAK int printf( const char* format, ... )
{
	va_list args;
	va_start( args, format );
	int ret_status = mini_vpprintf(__puts_uart, 0, format, args);
	va_end( args );
	return ret_status;
}

WEAK int vprintf(const char* format, va_list args)
{
	return mini_vpprintf(__puts_uart, 0, format, args);
}

WEAK int snprintf( char * buffer, unsigned int buffer_len, const char* format, ... )
{
	va_list args;
	va_start( args, format );
	int ret = mini_vsnprintf( buffer, buffer_len, format, args );
	va_end( args );
	return ret;
}

WEAK int sprintf( char * buffer, const char * format, ... )
{
	va_list args;
	va_start( args, format );
	int ret = mini_vsnprintf( buffer, INT_MAX, format, args );
	va_end( args );
	return ret;
}

/* Some stuff from MUSL


----------------------------------------------------------------------
Copyright © 2005-2020 Rich Felker, et al.

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
striction, including
without limitation the rights to use, copy, modify, merge, publish,
distribute, sublicense, and/or sell copies of the Software, and to
permit persons to whom the Software is furnished to do so, subject to
the following conditions:

The above copyright notice and this permission notice shall be
included in all copies or substantial portions of the Software.

THE SOFTWARE IS PROVIDED "AS IS", WITHOUT WARRANTY OF ANY KIND,
EXPRESS OR IMPLIED, INCLUDING BUT NOT LIMITED TO THE WARRANTIES OF
MERCHANTABILITY, FITNESS FOR A PARTICULAR PURPOSE AND NONINFRINGEMENT.
IN NO EVENT SHALL THE AUTHORS OR COPYRIGHT HOLDERS BE LIABLE FOR ANY
CLAIM, DAMAGES OR OTHER LIABILITY, WHETHER IN AN ACTION OF CONTRACT,
TORT OR OTHERWISE, ARISING FROM, OUT OF OR IN CONNECTION WITH THE
SOFTWARE OR THE USE OR OTHER DEALINGS IN THE SOFTWARE.
----------------------------------------------------------------------

*/

/*
 * mbstate_t is an opaque object to keep conversion state, during multibyte
 * stream conversions.  The content must not be referenced by user programs.
 */

#define CURRENT_UTF8 0
#define IS_CODEUNIT(c) ((unsigned)(c)-0xdf80 < 0x80)
#define MB_CUR_MAX (CURRENT_UTF8 ? 4 : 1)

typedef void * mbstate_t;

#ifdef UNICODE
WEAK size_t wcrtomb(char *restrict s, wchar_t wc, mbstate_t *restrict st)
{
	if (!s) return 1;
	if ((unsigned)wc < 0x80) {
		*s = wc;
		return 1;
	} else if (MB_CUR_MAX == 1) {
		if (!IS_CODEUNIT(wc)) {
			errno = 0x02; // EILSEQ
			return -1;
		}
		*s = wc;
		return 1;
	} else if ((unsigned)wc < 0x800) {
		*s++ = 0xc0 | (wc>>6);
		*s = 0x80 | (wc&0x3f);
		return 2;
	} else if ((unsigned)wc < 0xd800 || (unsigned)wc-0xe000 < 0x2000) {
		*s++ = 0xe0 | (wc>>12);
		*s++ = 0x80 | ((wc>>6)&0x3f);
		*s = 0x80 | (wc&0x3f);
		return 3;
	} else if ((unsigned)wc-0x10000 < 0x100000) {
		*s++ = 0xf0 | (wc>>18);
		*s++ = 0x80 | ((wc>>12)&0x3f);
		*s++ = 0x80 | ((wc>>6)&0x3f);
		*s = 0x80 | (wc&0x3f);
		return 4;
	}
	errno = 0x02;//EILSEQ;
	return -1;
}
WEAK int wctomb(char *s, wchar_t wc)
{
	if (!s) return 0;
	return wcrtomb(s, wc, 0);
}
#endif
WEAK size_t strlen(const char *s)
{
	const char *a = s;
	for (; *s; s++);
	return s-a;
}
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

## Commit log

2026-02-03 added schematic
    [uart_data_logger.kicad_pcb, uart_data_logger.kicad_sch]
2026-02-03 Initial work in progress version
    [config.txt]
2026-02-12 optimization for continuous stream of data.
    - write cache
    - fixed decimal/hexadecimal logging
    - build config to choose reload options.
    [config.txt]
2026-02-15 Added Tests and fixed RTC init issue.
    [uart_logger.c]
2026-02-25 fix for empty 0KB log files
    [drv_psuedo_rtc.c, uart_logger.c]
2026-02-27 fixed logging failure
    1. improved SD driver writing speed
    2. timing resolution changed to 50ms
    3. LED error blink rate changed to 0.5Hz
    4. buffer handling issue.
    [app_base.h, drv_psuedo_rtc.c, drv_sd_mmc.c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]
2026-03-04 code clean-up, aligned write.
    - log streamlining
    - improved periodic sync
    - sector aligned io-write
    - fix for random disk_write failures
    [config.txt]
2026-03-23 Fixed spurious SD write failure
    1. SPI Tx/Rx DMA priority fix
    2. nested systick support
    3. improved error status reporting
    [app_base.h, ch32fun.c, drv_sd_mmc.c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]
2026-04-01 updated schematics/layout.
    [uart_data_logger.kicad_pcb, uart_data_logger.kicad_sch]

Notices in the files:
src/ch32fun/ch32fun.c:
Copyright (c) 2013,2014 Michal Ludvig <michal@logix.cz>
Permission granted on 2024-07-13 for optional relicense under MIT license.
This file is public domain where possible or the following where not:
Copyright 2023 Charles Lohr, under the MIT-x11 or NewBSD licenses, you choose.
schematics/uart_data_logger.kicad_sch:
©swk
